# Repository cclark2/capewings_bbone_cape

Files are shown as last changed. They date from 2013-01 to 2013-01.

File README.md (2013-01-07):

CapeWings BeagleBone Cape
=========================

Breaks down cape stacks into a form factor easier to debug without having to keep removing capes. Supports selectively jumpering signals between the BeagleBone and up to three capes. Also allows multiple BeagleBones to be connected together. It's a cape developer's dream!

Special thanks to <a href="http://www.sparkfun.com/">SparkFun</a> for use of their open-source EAGLE libraries.

## Project Links
- <a href="http://www.hitchhikeree.org/beaglebone_capes/capewings/">HitchhikerEE page</a>
- <a href="http://www.youtube.com/watch?v=Ci1aKsf_dBM">YouTube video</a>
- <a href="https://docs.google.com/folder/d/0B5HjtPsFD8u5NXZ3VUFZem5UdW8/edit">Design files on Google Drive</a>
- <a href="http://beagleboard.org/CapeContest/entries/CapeWings/">BeagleBone Cape Contest page</a>

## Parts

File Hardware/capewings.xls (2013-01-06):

Qty | Value | Device | Package | Parts | Description | MPN | Price | Total
7 |  | FE05-2 | FE05-2 | P1, P4, P6, P10, P13, P16, P19 | FEMALE HEADER | SSHQ-105-D-10-GT-LF | $0.50 | $3.50
14 |  | FE23-2 | FE23-2 | P2, P3, P5, P7, P8, P9, P11, P12, P14, P15, P17, P18, P20, P21 | FEMALE HEADER | SSHQ-123-D-10-GT-LF | 2.28 | 31.92
12 |  | HOLE | HOLE | H1, H2, H3, H4, H5, H6, H7, H8, H9, H10, H11, H12 |  |  |  | 0
3 | 150 | R-US_R0603 | R0603 | R2, R5, R33 | RESISTOR, American symbol | 302-150-RC | 0.04 | 0.12
3 | 50 | R-US_R0603 | R0603 | R3, R6, R34 | RESISTOR, American symbol | 302-49.9-RC | 0.04 | 0.12
3 | 60 | R-US_R0603 | R0603 | R1, R4, R7 | RESISTOR, American symbol | 302-60.4-RC | 0.04 | 0.12
3 | blue | LEDCHIPLED_0603 | CHIPLED_0603 | LED1, LED4, LED7 | LED | HT-193NB-5589 | 0.15 | 0.45
3 | green | LEDCHIPLED_0603 | CHIPLED_0603 | LED2, LED5, LED8 | LED | LG Q971-KN-1 | 0.1 | 0.3
3 | vdd_blue | LEDCHIPLED_0603 | CHIPLED_0603 | LED3, LED6, LED9 | LED | VLMB1300-GS08 | 0.11 | 0.33
 |  |  |  |  |  |  |  | $36.86
 |  |  |  |  |  | Need a couple hundred jumpers

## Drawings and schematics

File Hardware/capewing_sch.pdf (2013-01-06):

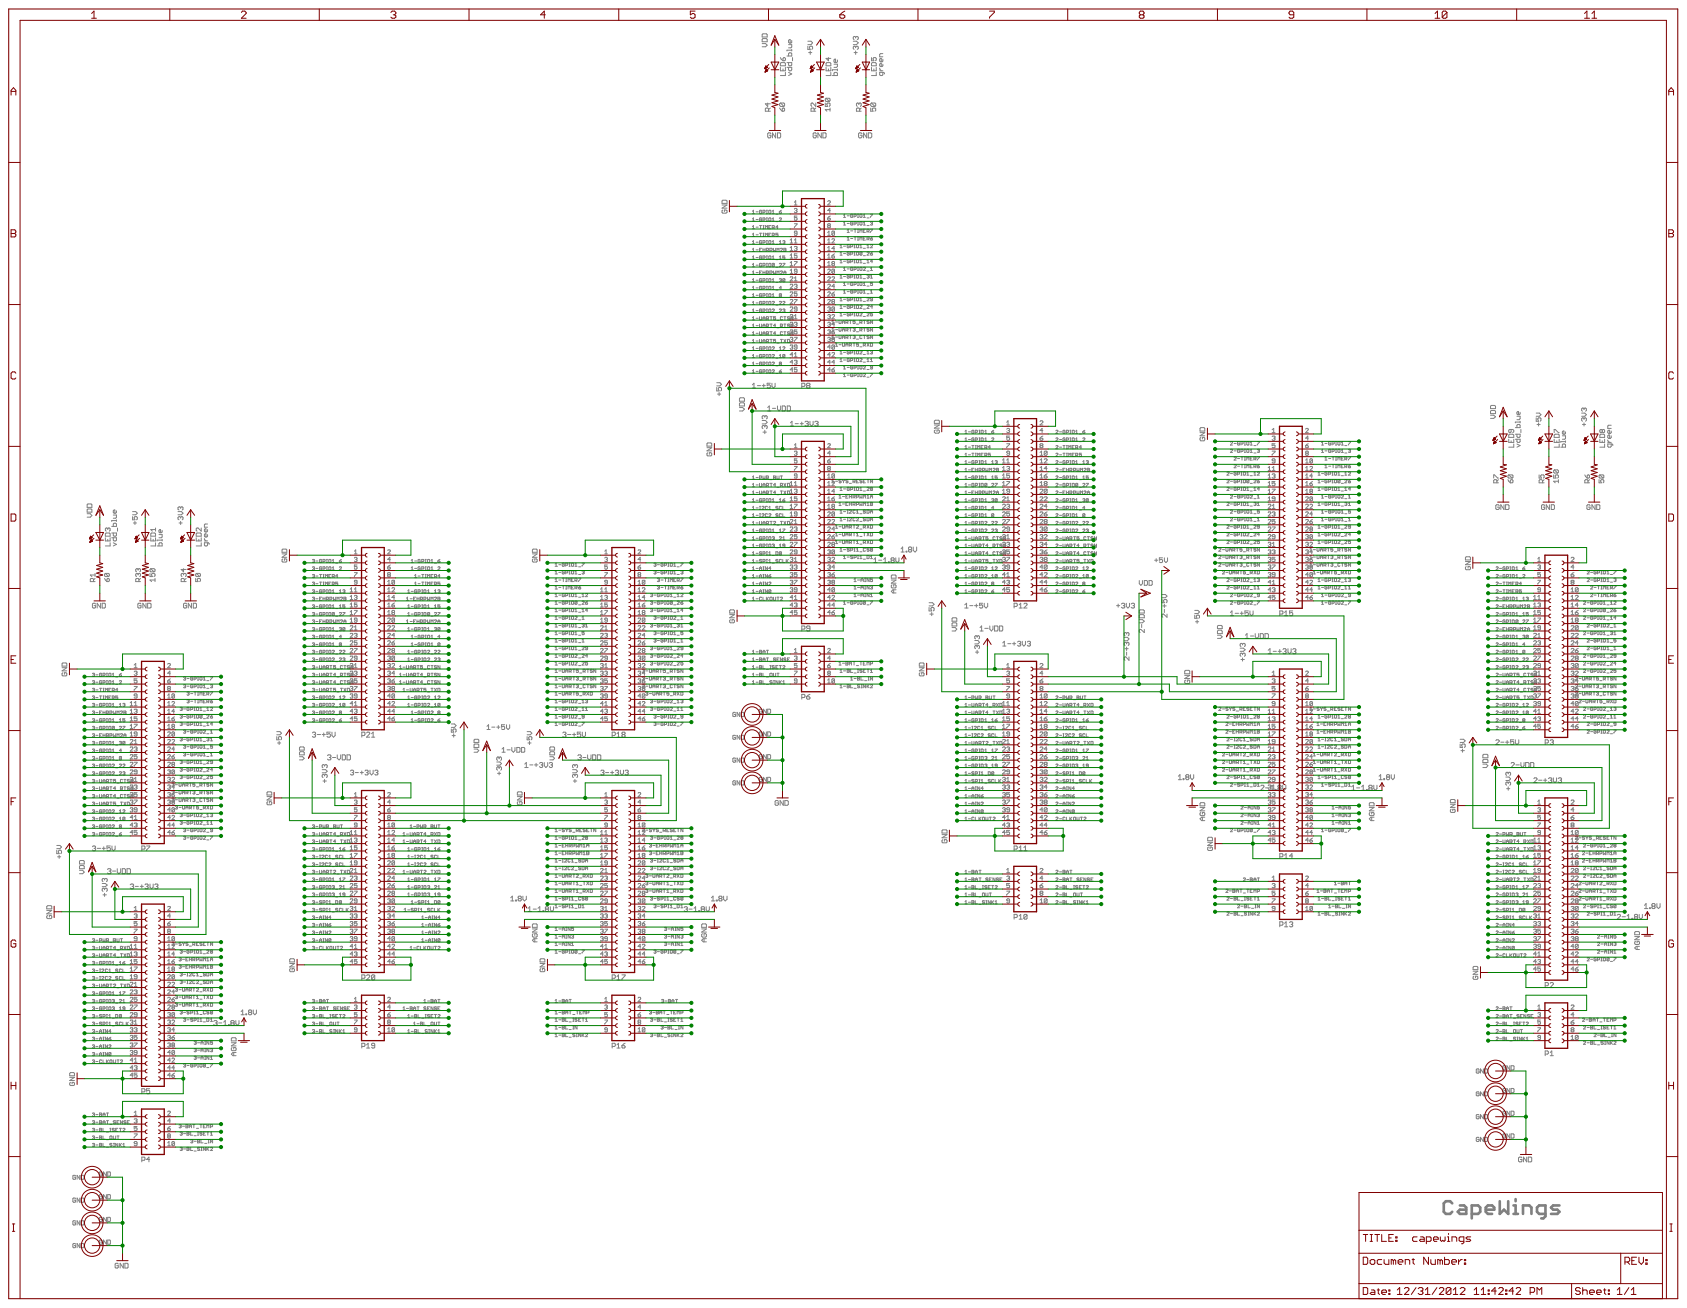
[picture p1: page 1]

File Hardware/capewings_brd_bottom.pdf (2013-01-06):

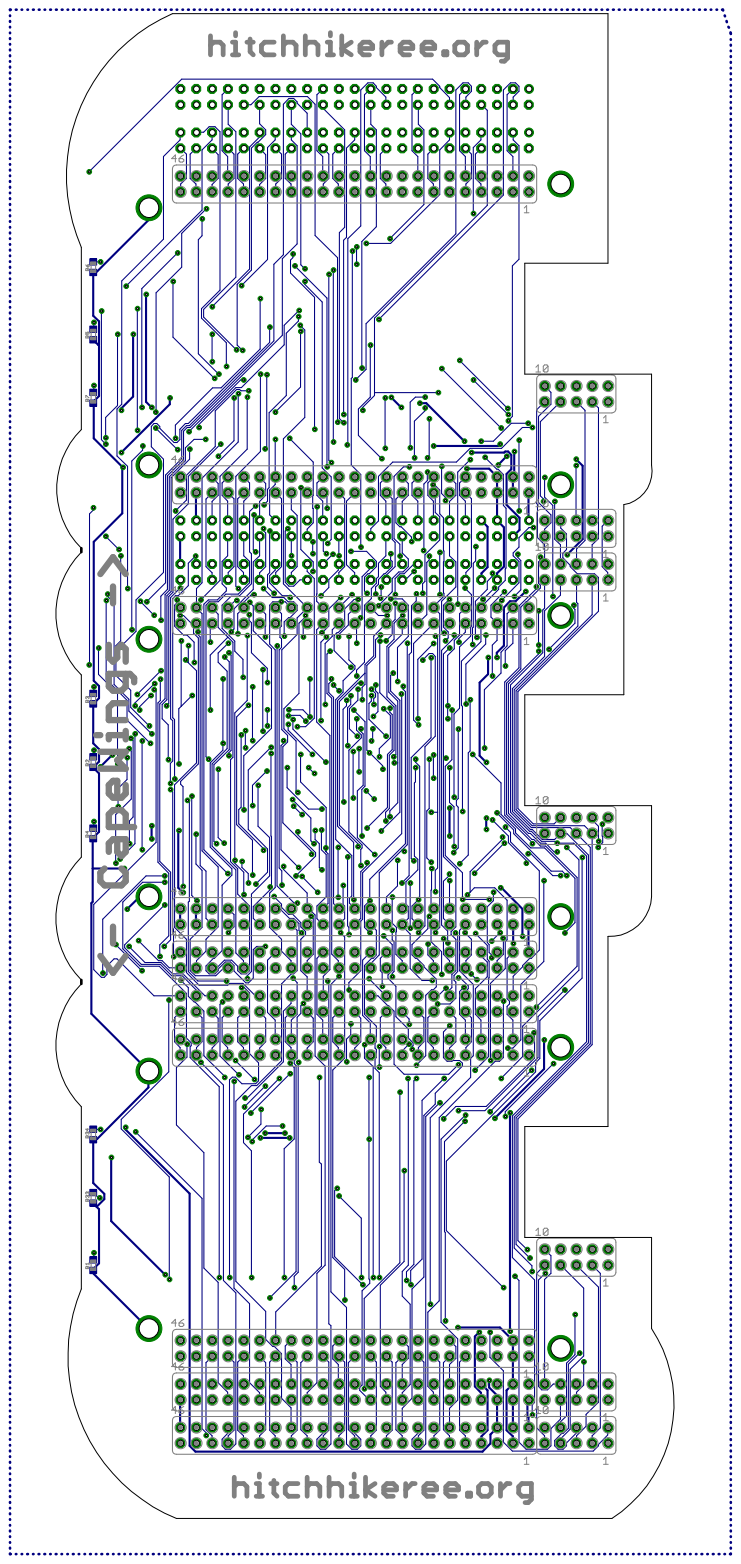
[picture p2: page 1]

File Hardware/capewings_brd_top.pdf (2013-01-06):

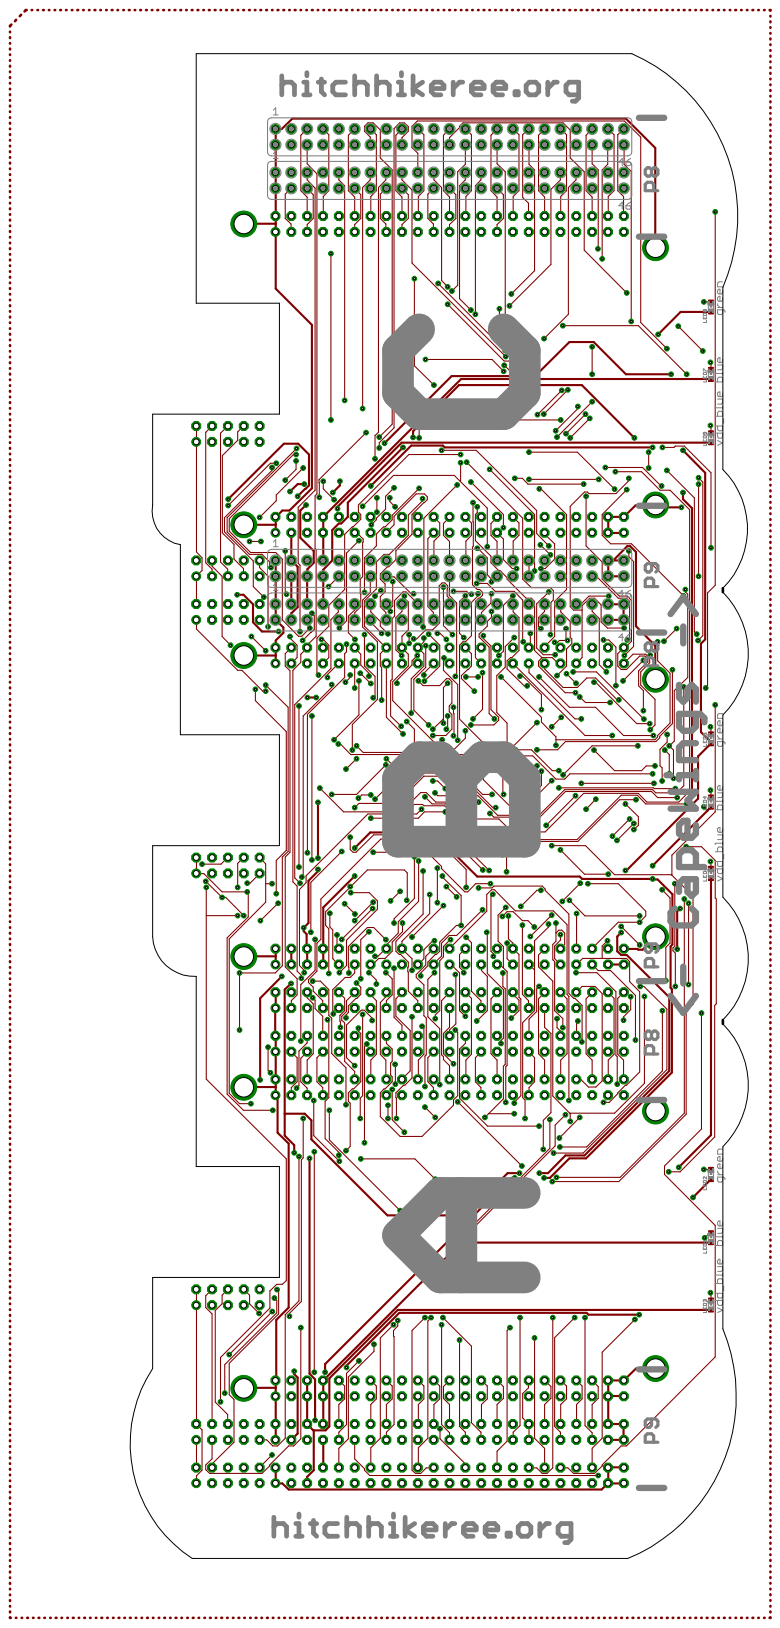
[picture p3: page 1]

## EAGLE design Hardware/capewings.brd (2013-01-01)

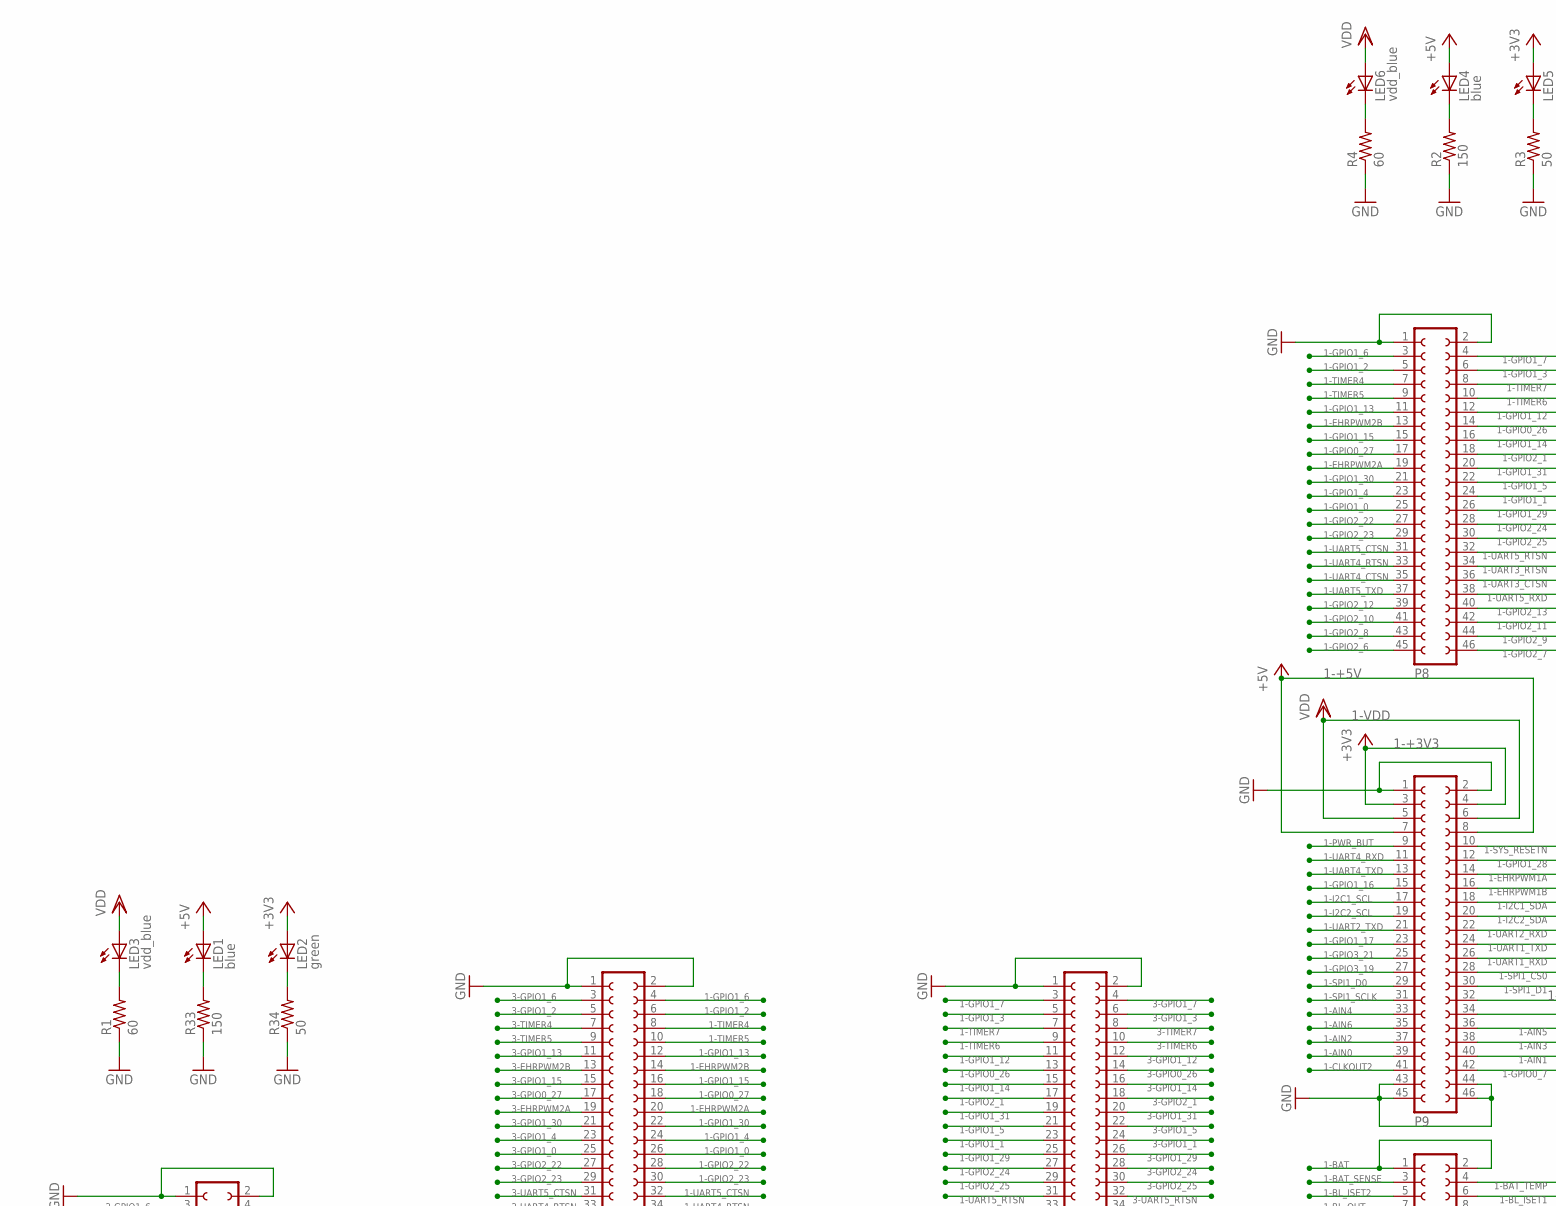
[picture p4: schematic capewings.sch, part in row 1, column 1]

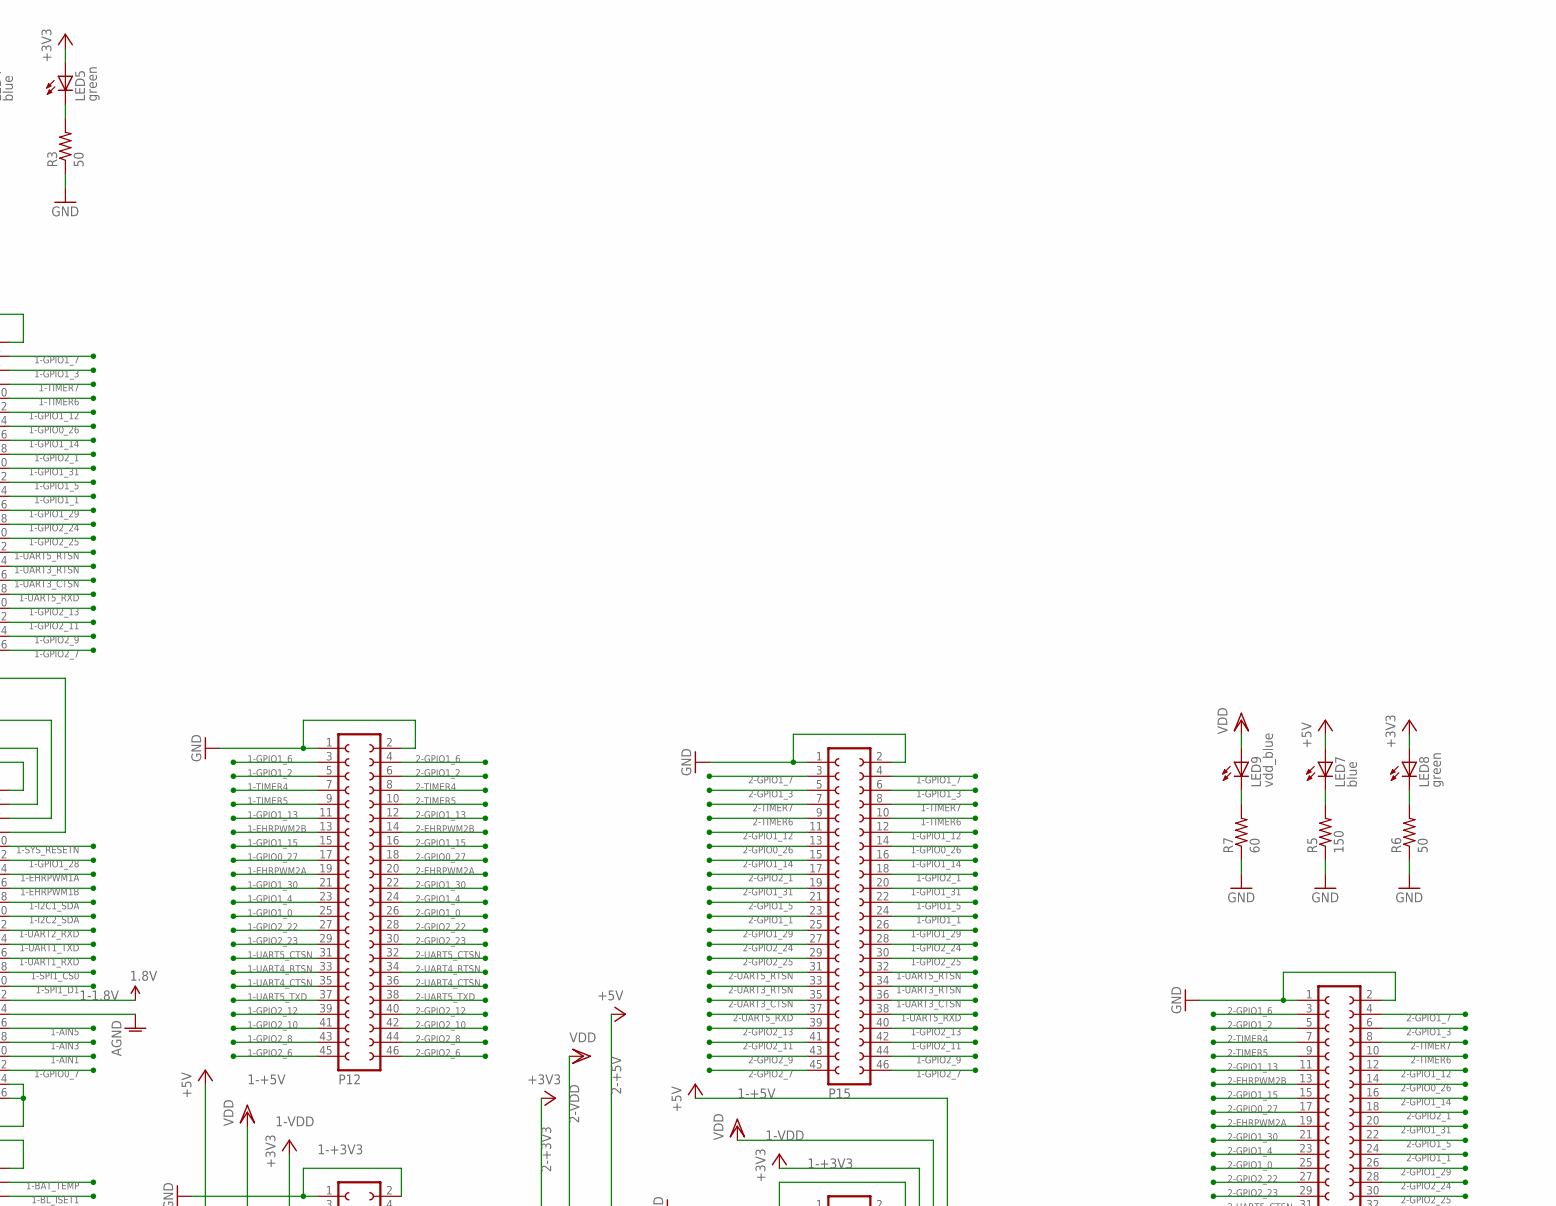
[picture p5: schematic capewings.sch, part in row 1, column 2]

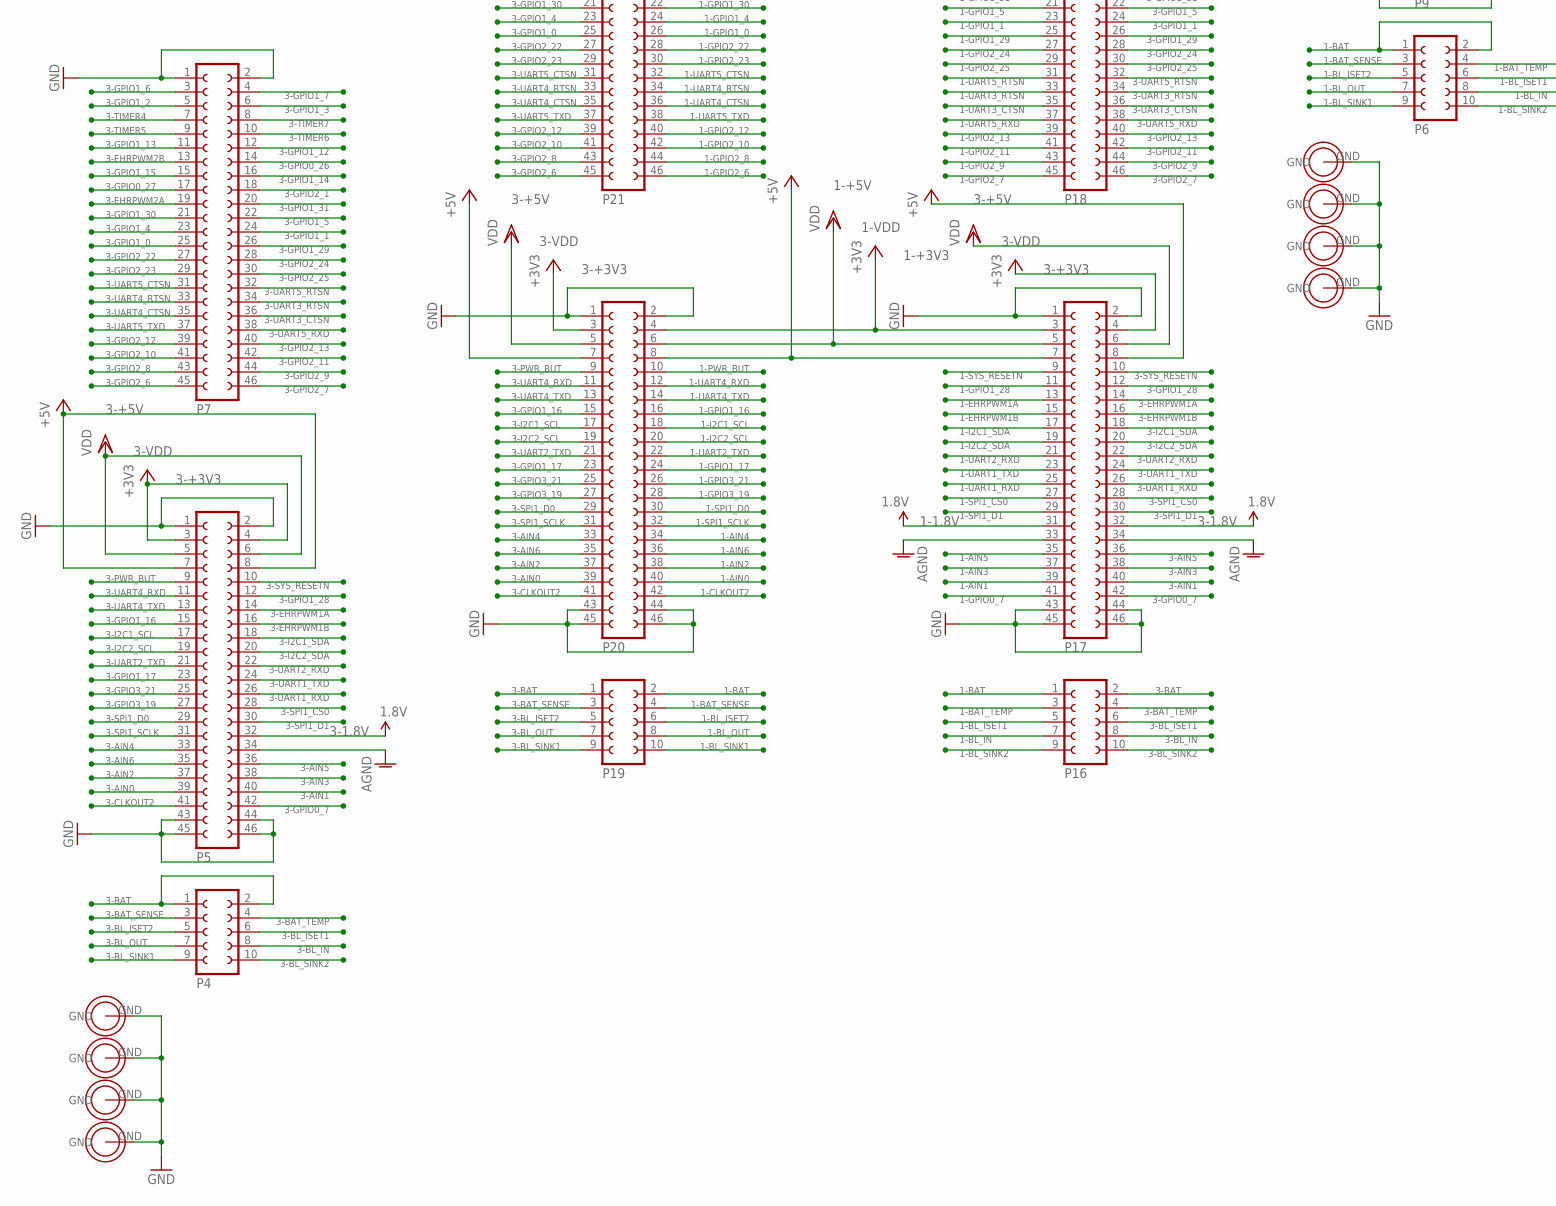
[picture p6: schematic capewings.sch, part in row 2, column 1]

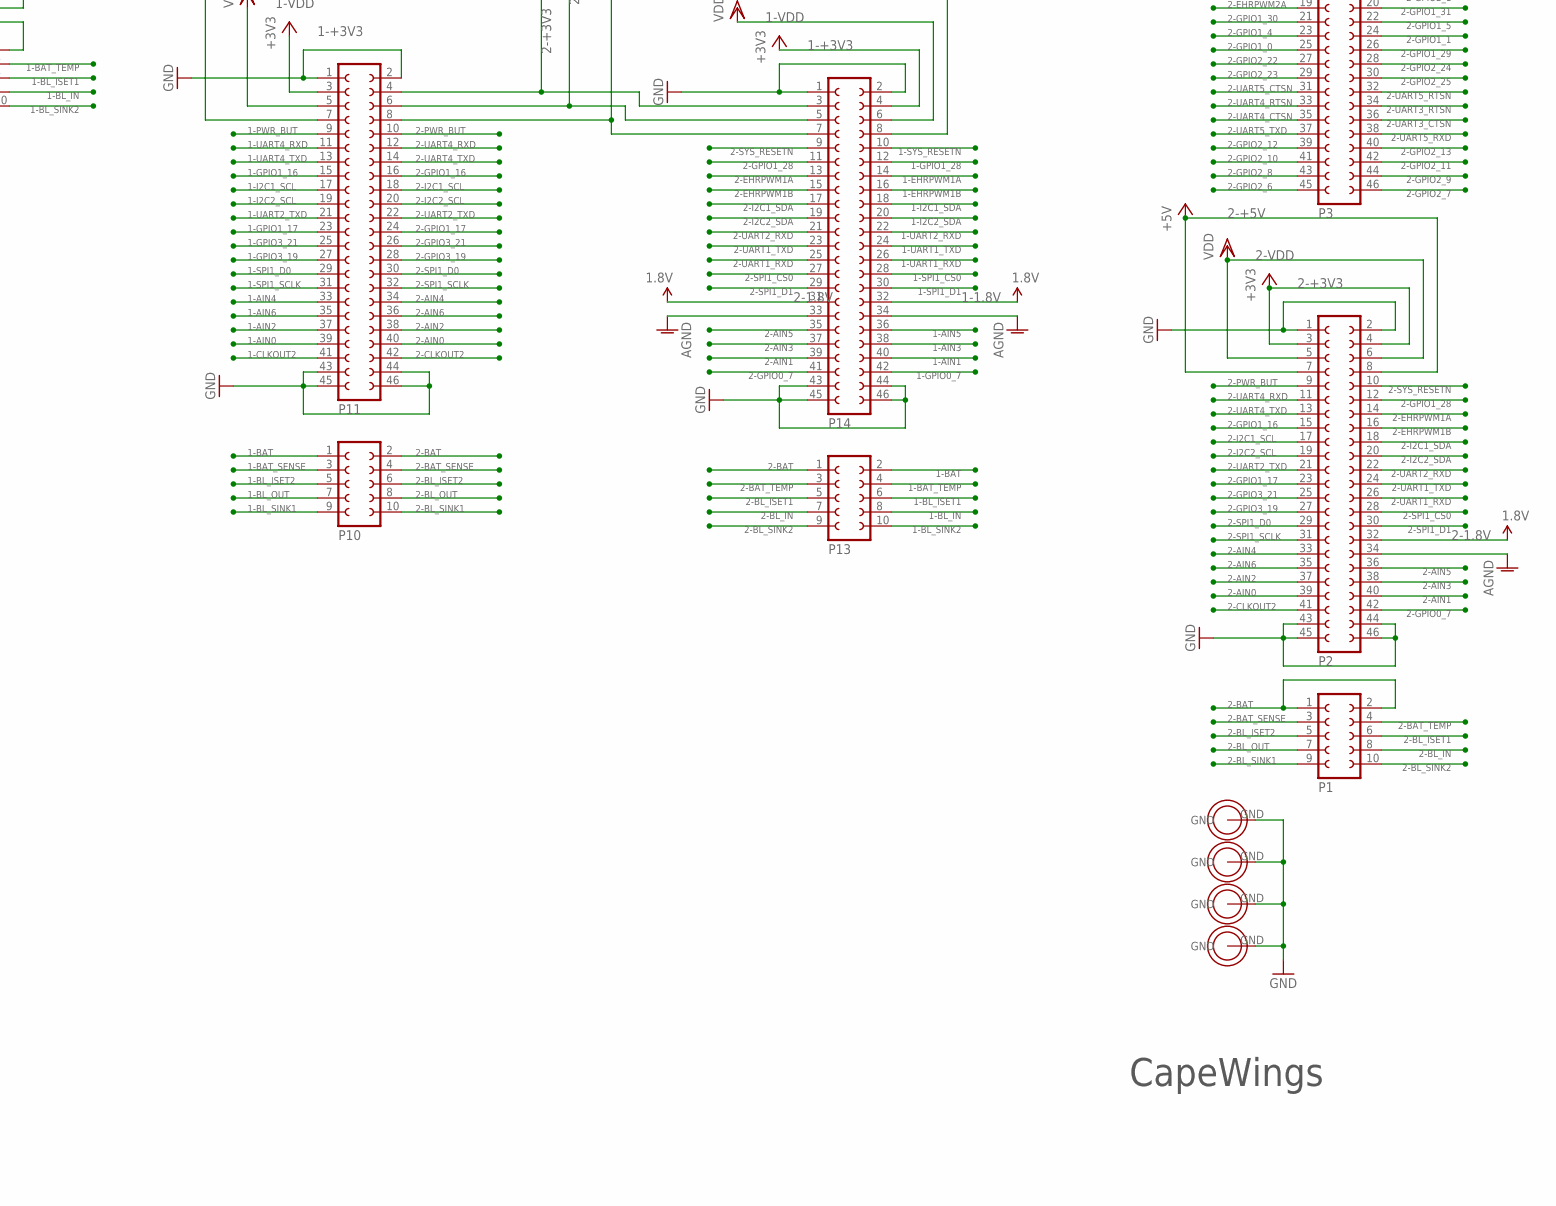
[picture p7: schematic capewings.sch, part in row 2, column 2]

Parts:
H1, H2, H3, H4, H5, H6, H7, H8, H9, H10, H11, H12: HOLE
LED1, LED4, LED7: blue; CHIPLED_0603; MPN HT-193NB-5589
LED2, LED5, LED8: green; CHIPLED_0603; MPN LG Q971-KN-1
LED3, LED6, LED9: vdd_blue; CHIPLED_0603; MPN VLMB1300-GS08
P1, P4, P6: FE05-2; MPN SSHQ-105-D-10-GT-LF
P2, P3, P5, P7, P8, P9: FE23-2; MPN SSHQ-123-D-10-GT-LF
P10, P13, P16, P19: FE05-2; MPN TSHC-105-D-03-145-GT-LF
P11, P12, P14, P15, P17, P18, P20, P21: FE23-2; MPN TSHC-123-D-03-145-GT-LF
R1, R4, R7: 60; R0603; MPN 302-60.4-RC
R2, R5, R33: 150; R0603; MPN 302-150-RC
R3, R6, R34: 50; R0603; MPN 302-49.9-RC

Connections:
1-1.8V: P9.32, P14.32, P17.31
1-+3V3: LED5.A, P9.3, P9.4, P11.3, P14.4, P17.3, P20.4
1-+5V: LED4.A, P9.7, P9.8, P11.7, P14.8, P17.7, P20.8
1-AIN0: P9.39, P11.39, P20.40
1-AIN1: P9.40, P14.40, P17.39
1-AIN2: P9.37, P11.37, P20.38
1-AIN3: P9.38, P14.38, P17.37
1-AIN4: P9.33, P11.33, P20.34
1-AIN5: P9.36, P14.36, P17.35
1-AIN6: P9.35, P11.35, P20.36
1-BAT: P6.1, P6.2, P10.1, P13.2, P16.1, P19.2
1-BAT_SENSE: P6.3, P10.3, P19.4
1-BAT_TEMP: P6.4, P13.4, P16.3
1-BL_IN: P6.8, P13.8, P16.7
1-BL_ISET1: P6.6, P13.6, P16.5
1-BL_ISET2: P6.5, P10.5, P19.6
1-BL_OUT: P6.7, P10.7, P19.8
1-BL_SINK1: P6.9, P10.9, P19.10
1-BL_SINK2: P6.10, P13.10, P16.9
1-CLKOUT2: P9.41, P11.41, P20.42
1-EHRPWM1A: P9.14, P14.14, P17.13
1-EHRPWM1B: P9.16, P14.16, P17.15
1-EHRPWM2A: P8.19, P12.19, P21.20
1-EHRPWM2B: P8.13, P12.13, P21.14
1-GPIO0_7: P9.42, P14.42, P17.41
1-GPIO0_26: P8.14, P15.14, P18.13
1-GPIO0_27: P8.17, P12.17, P21.18
1-GPIO1_0: P8.25, P12.25, P21.26
1-GPIO1_1: P8.24, P15.24, P18.23
1-GPIO1_2: P8.5, P12.5, P21.6
1-GPIO1_3: P8.6, P15.6, P18.5
1-GPIO1_4: P8.23, P12.23, P21.24
1-GPIO1_5: P8.22, P15.22, P18.21
1-GPIO1_6: P8.3, P12.3, P21.4
1-GPIO1_7: P8.4, P15.4, P18.3
1-GPIO1_12: P8.12, P15.12, P18.11
1-GPIO1_13: P8.11, P12.11, P21.12
1-GPIO1_14: P8.16, P15.16, P18.15
1-GPIO1_15: P8.15, P12.15, P21.16
1-GPIO1_16: P9.15, P11.15, P20.16
1-GPIO1_17: P9.23, P11.23, P20.24
1-GPIO1_28: P9.12, P14.12, P17.11
1-GPIO1_29: P8.26, P15.26, P18.25
1-GPIO1_30: P8.21, P12.21, P21.22
1-GPIO1_31: P8.20, P15.20, P18.19
1-GPIO2_1: P8.18, P15.18, P18.17
1-GPIO2_6: P8.45, P12.45, P21.46
1-GPIO2_7: P8.46, P15.46, P18.45
1-GPIO2_8: P8.43, P12.43, P21.44
1-GPIO2_9: P8.44, P15.44, P18.43
1-GPIO2_10: P8.41, P12.41, P21.42
1-GPIO2_11: P8.42, P15.42, P18.41
1-GPIO2_12: P8.39, P12.39, P21.40
1-GPIO2_13: P8.40, P15.40, P18.39
1-GPIO2_22: P8.27, P12.27, P21.28
1-GPIO2_23: P8.29, P12.29, P21.30
1-GPIO2_24: P8.28, P15.28, P18.27
1-GPIO2_25: P8.30, P15.30, P18.29
1-GPIO3_19: P9.27, P11.27, P20.28
1-GPIO3_21: P9.25, P11.25, P20.26
1-I2C1_SCL: P9.17, P11.17, P20.18
1-I2C1_SDA: P9.18, P14.18, P17.17
1-I2C2_SCL: P9.19, P11.19, P20.20
1-I2C2_SDA: P9.20, P14.20, P17.19
1-PWR_BUT: P9.9, P11.9, P20.10
1-SPI1_CS0: P9.28, P14.28, P17.27
1-SPI1_D0: P9.29, P11.29, P20.30
1-SPI1_D1: P9.30, P14.30, P17.29
1-SPI1_SCLK: P9.31, P11.31, P20.32
1-SYS_RESETN: P9.10, P14.10, P17.9
1-TIMER4: P8.7, P12.7, P21.8
1-TIMER5: P8.9, P12.9, P21.10
1-TIMER6: P8.10, P15.10, P18.9
1-TIMER7: P8.8, P15.8, P18.7
1-UART1_RXD: P9.26, P14.26, P17.25
1-UART1_TXD: P9.24, P14.24, P17.23
1-UART2_RXD: P9.22, P14.22, P17.21
1-UART2_TXD: P9.21, P11.21, P20.22
1-UART3_CTSN: P8.36, P15.36, P18.35
1-UART3_RTSN: P8.34, P15.34, P18.33
1-UART4_CTSN: P8.35, P12.35, P21.36
1-UART4_RTSN: P8.33, P12.33, P21.34
1-UART4_RXD: P9.11, P11.11, P20.12
1-UART4_TXD: P9.13, P11.13, P20.14
1-UART5_CTSN: P8.31, P12.31, P21.32
1-UART5_RTSN: P8.32, P15.32, P18.31
1-UART5_RXD: P8.38, P15.38, P18.37
1-UART5_TXD: P8.37, P12.37, P21.38
1-VDD: LED6.A, P9.5, P9.6, P11.5, P14.6, P17.5, P20.6
2-1.8V: P2.32, P14.31
2-+3V3: LED8.A, P2.3, P2.4, P11.4, P14.3
2-+5V: LED7.A, P2.7, P2.8, P11.8, P14.7
2-AIN0: P2.39, P11.40
2-AIN1: P2.40, P14.39
2-AIN2: P2.37, P11.38
2-AIN3: P2.38, P14.37
2-AIN4: P2.33, P11.34
2-AIN5: P2.36, P14.35
2-AIN6: P2.35, P11.36
2-BAT: P1.1, P1.2, P10.2, P13.1
2-BAT_SENSE: P1.3, P10.4
2-BAT_TEMP: P1.4, P13.3
2-BL_IN: P1.8, P13.7
2-BL_ISET1: P1.6, P13.5
2-BL_ISET2: P1.5, P10.6
2-BL_OUT: P1.7, P10.8
2-BL_SINK1: P1.9, P10.10
2-BL_SINK2: P1.10, P13.9
2-CLKOUT2: P2.41, P11.42
2-EHRPWM1A: P2.14, P14.13
2-EHRPWM1B: P2.16, P14.15
2-EHRPWM2A: P3.19, P12.20
2-EHRPWM2B: P3.13, P12.14
2-GPIO0_7: P2.42, P14.41
2-GPIO0_26: P3.14, P15.13
2-GPIO0_27: P3.17, P12.18
2-GPIO1_0: P3.25, P12.26
2-GPIO1_1: P3.24, P15.23
2-GPIO1_2: P3.5, P12.6
2-GPIO1_3: P3.6, P15.5
2-GPIO1_4: P3.23, P12.24
2-GPIO1_5: P3.22, P15.21
2-GPIO1_6: P3.3, P12.4
2-GPIO1_7: P3.4, P15.3
2-GPIO1_12: P3.12, P15.11
2-GPIO1_13: P3.11, P12.12
2-GPIO1_14: P3.16, P15.15
2-GPIO1_15: P3.15, P12.16
2-GPIO1_16: P2.15, P11.16
2-GPIO1_17: P2.23, P11.24
2-GPIO1_28: P2.12, P14.11
2-GPIO1_29: P3.26, P15.25
2-GPIO1_30: P3.21, P12.22
2-GPIO1_31: P3.20, P15.19
2-GPIO2_1: P3.18, P15.17
2-GPIO2_6: P3.45, P12.46
2-GPIO2_7: P3.46, P15.45
2-GPIO2_8: P3.43, P12.44
2-GPIO2_9: P3.44, P15.43
2-GPIO2_10: P3.41, P12.42
2-GPIO2_11: P3.42, P15.41
2-GPIO2_12: P3.39, P12.40
2-GPIO2_13: P3.40, P15.39
2-GPIO2_22: P3.27, P12.28
2-GPIO2_23: P3.29, P12.30
2-GPIO2_24: P3.28, P15.27
2-GPIO2_25: P3.30, P15.29
2-GPIO3_19: P2.27, P11.28
2-GPIO3_21: P2.25, P11.26
2-I2C1_SCL: P2.17, P11.18
2-I2C1_SDA: P2.18, P14.17
2-I2C2_SCL: P2.19, P11.20
2-I2C2_SDA: P2.20, P14.19
2-PWR_BUT: P2.9, P11.10
2-SPI1_CS0: P2.28, P14.27
2-SPI1_D0: P2.29, P11.30
2-SPI1_D1: P2.30, P14.29
2-SPI1_SCLK: P2.31, P11.32
2-SYS_RESETN: P2.10, P14.9
2-TIMER4: P3.7, P12.8
2-TIMER5: P3.9, P12.10
2-TIMER6: P3.10, P15.9
2-TIMER7: P3.8, P15.7
2-UART1_RXD: P2.26, P14.25
2-UART1_TXD: P2.24, P14.23
2-UART2_RXD: P2.22, P14.21
2-UART2_TXD: P2.21, P11.22
2-UART3_CTSN: P3.36, P15.35
2-UART3_RTSN: P3.34, P15.33
2-UART4_CTSN: P3.35, P12.36
2-UART4_RTSN: P3.33, P12.34
2-UART4_RXD: P2.11, P11.12
2-UART4_TXD: P2.13, P11.14
2-UART5_CTSN: P3.31, P12.32
2-UART5_RTSN: P3.32, P15.31
2-UART5_RXD: P3.38, P15.37
2-UART5_TXD: P3.37, P12.38
2-VDD: LED9.A, P2.5, P2.6, P11.6, P14.5
3-1.8V: P5.32, P17.32
3-+3V3: LED2.A, P5.3, P5.4, P17.4, P20.3
3-+5V: LED1.A, P5.7, P5.8, P17.8, P20.7
3-AIN0: P5.39, P20.39
3-AIN1: P5.40, P17.40
3-AIN2: P5.37, P20.37
3-AIN3: P5.38, P17.38
3-AIN4: P5.33, P20.33
3-AIN5: P5.36, P17.36
3-AIN6: P5.35, P20.35
3-BAT: P4.1, P4.2, P16.2, P19.1
3-BAT_SENSE: P4.3, P19.3
3-BAT_TEMP: P4.4, P16.4
3-BL_IN: P4.8, P16.8
3-BL_ISET1: P4.6, P16.6
3-BL_ISET2: P4.5, P19.5
3-BL_OUT: P4.7, P19.7
3-BL_SINK1: P4.9, P19.9
3-BL_SINK2: P4.10, P16.10
3-CLKOUT2: P5.41, P20.41
3-EHRPWM1A: P5.14, P17.14
3-EHRPWM1B: P5.16, P17.16
3-EHRPWM2A: P7.19, P21.19
3-EHRPWM2B: P7.13, P21.13
3-GPIO0_7: P5.42, P17.42
3-GPIO0_26: P7.14, P18.14
3-GPIO0_27: P7.17, P21.17
3-GPIO1_0: P7.25, P21.25
3-GPIO1_1: P7.24, P18.24
3-GPIO1_2: P7.5, P21.5
3-GPIO1_3: P7.6, P18.6
3-GPIO1_4: P7.23, P21.23
3-GPIO1_5: P7.22, P18.22
3-GPIO1_6: P7.3, P21.3
3-GPIO1_7: P7.4, P18.4
3-GPIO1_12: P7.12, P18.12
3-GPIO1_13: P7.11, P21.11
3-GPIO1_14: P7.16, P18.16
3-GPIO1_15: P7.15, P21.15
3-GPIO1_16: P5.15, P20.15
3-GPIO1_17: P5.23, P20.23
3-GPIO1_28: P5.12, P17.12
3-GPIO1_29: P7.26, P18.26
3-GPIO1_30: P7.21, P21.21
3-GPIO1_31: P7.20, P18.20
3-GPIO2_1: P7.18, P18.18
3-GPIO2_6: P7.45, P21.45
3-GPIO2_7: P7.46, P18.46
3-GPIO2_8: P7.43, P21.43
3-GPIO2_9: P7.44, P18.44
3-GPIO2_10: P7.41, P21.41
3-GPIO2_11: P7.42, P18.42
3-GPIO2_12: P7.39, P21.39
3-GPIO2_13: P7.40, P18.40
3-GPIO2_22: P7.27, P21.27
3-GPIO2_23: P7.29, P21.29
3-GPIO2_24: P7.28, P18.28
3-GPIO2_25: P7.30, P18.30
3-GPIO3_19: P5.27, P20.27
3-GPIO3_21: P5.25, P20.25
3-I2C1_SCL: P5.17, P20.17
3-I2C1_SDA: P5.18, P17.18
3-I2C2_SCL: P5.19, P20.19
3-I2C2_SDA: P5.20, P17.20
3-PWR_BUT: P5.9, P20.9
3-SPI1_CS0: P5.28, P17.28
3-SPI1_D0: P5.29, P20.29
3-SPI1_D1: P5.30, P17.30
3-SPI1_SCLK: P5.31, P20.31
3-SYS_RESETN: P5.10, P17.10
3-TIMER4: P7.7, P21.7
3-TIMER5: P7.9, P21.9
3-TIMER6: P7.10, P18.10
3-TIMER7: P7.8, P18.8
3-UART1_RXD: P5.26, P17.26
3-UART1_TXD: P5.24, P17.24
3-UART2_RXD: P5.22, P17.22
3-UART2_TXD: P5.21, P20.21
3-UART3_CTSN: P7.36, P18.36
3-UART3_RTSN: P7.34, P18.34
3-UART4_CTSN: P7.35, P21.35
3-UART4_RTSN: P7.33, P21.33
3-UART4_RXD: P5.11, P20.11
3-UART4_TXD: P5.13, P20.13
3-UART5_CTSN: P7.31, P21.31
3-UART5_RTSN: P7.32, P18.32
3-UART5_RXD: P7.38, P18.38
3-UART5_TXD: P7.37, P21.37
3-VDD: LED3.A, P5.5, P5.6, P17.6, P20.5
AGND: P2.34, P5.34, P9.34, P14.33, P14.34, P17.33, P17.34
GND: H1.GND, H2.GND, H3.GND, H4.GND, H5.GND, H6.GND, H7.GND, H8.GND, H9.GND, H10.GND, H11.GND, H12.GND, P2.1, P2.2, P2.43, P2.44, P2.45, P2.46, P3.1, P3.2, P5.1, P5.2, P5.43, P5.44, P5.45, P5.46, P7.1, P7.2, P8.1, P8.2, P9.1, P9.2, P9.43, P9.44, P9.45, P9.46, P11.1, P11.2, P11.43, P11.44, P11.45, P11.46, P12.1, P12.2, P14.1, P14.2, P14.43, P14.44, P14.45, P14.46, P15.1, P15.2, P17.1, P17.2, P17.43, P17.44, P17.45, P17.46, P18.1, P18.2, P20.1, P20.2, P20.43, P20.44, P20.45, P20.46, P21.1, P21.2, R1.1, R2.1, R3.1, R4.1, R5.1, R6.1, R7.1, R33.1, R34.1
unnamed: LED3.C, R1.2
unnamed: LED4.C, R2.2
unnamed: LED5.C, R3.2
unnamed: LED6.C, R4.2
unnamed: LED7.C, R5.2
unnamed: LED8.C, R6.2
unnamed: LED9.C, R7.2
unnamed: LED1.C, R33.2
unnamed: LED2.C, R34.2

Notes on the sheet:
CapeWings

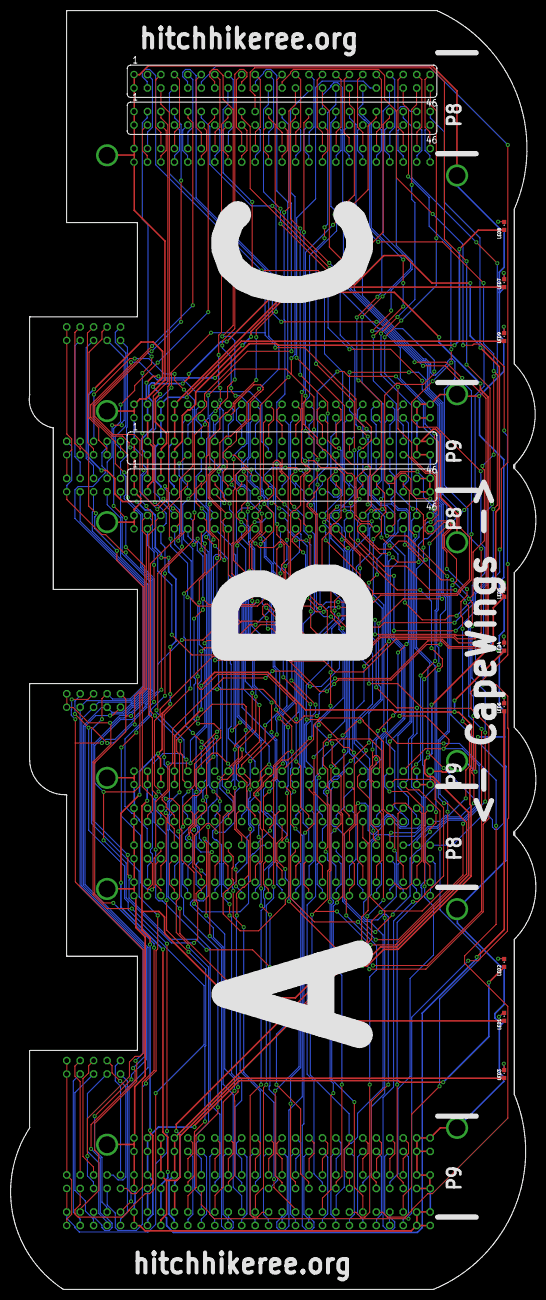
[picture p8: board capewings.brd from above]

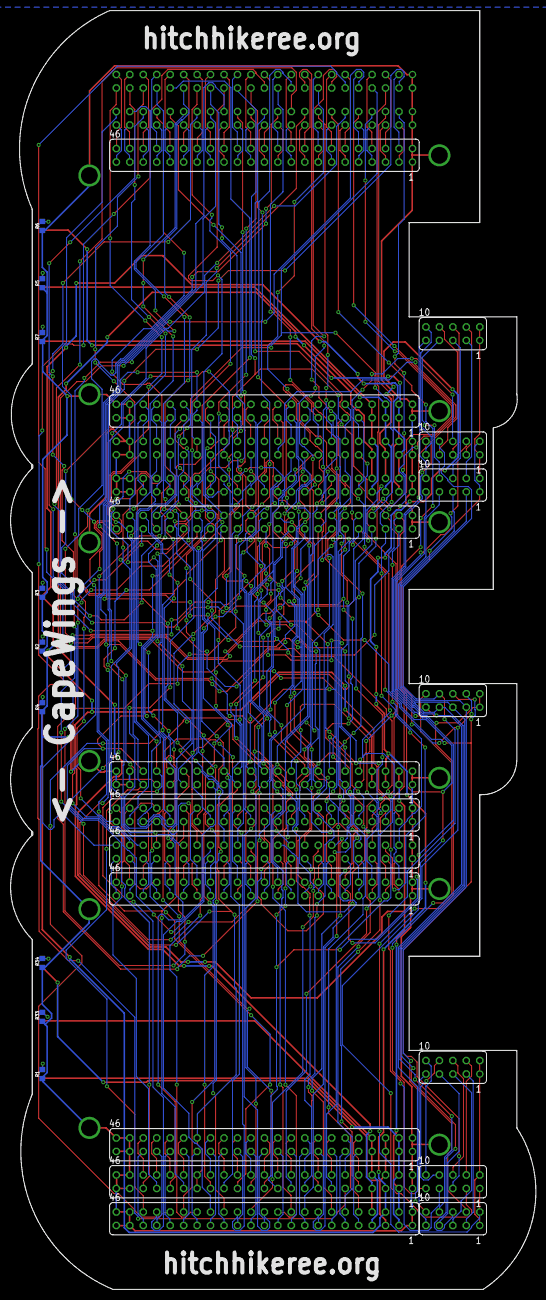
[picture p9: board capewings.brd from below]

Board: 2 copper layers, 99.1 x 241.3 mm, 51 parts (26 on the bottom side), 278 nets.

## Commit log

2013-01-01 Design complete, cleanup needed.
    [capewings.brd, capewings.sch, capewings.xlsx]
2013-01-01 BOM done.
    [capewings.brd, capewings.sch, capewings.xls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]
2013-01-06 Added BOM prices, added PDFs of design, sorted files.
    [capewings.brd, capewings.sch, capewings.xls]
2013-01-06 Fixing BOM formatting.
    [capewings.xls]
2013-01-06 One last format fix.
    [capewings.xls]
2013-01-06 BOM update.
    [capewings.xls]
